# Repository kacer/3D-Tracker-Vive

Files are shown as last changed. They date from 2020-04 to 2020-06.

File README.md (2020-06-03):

# 3D Tracker compatible with HTC Vive
This little device is capable of tracking its position in the world. The tracked position is then sent over BLE to the smartphone. The [mobile app](https://github.com/kacer/3D-Tracker-Vive-Android) was created for this purpose and renders the positions of all connected 3D trackers. For tracking 3D Tracker uses two HTC Base Stations which are part of the HTC Vive set for VR. For now, the tracker uses HTC Base Station 1.0 but HW is ready for HTC Base Station 2.0. This project came to the world within my master's thesis. The idea of position calculation is based on repo [vive-diy-position-sensor](https://github.com/ashtuchkin/vive-diy-position-sensor). 

The dimensions of the 3D tracker are 6.3x4.7 cm and can be worn like a watch. The 3D tracker itself looks: 
| Tracker1 | Tracker |
| --- | --- |

The demo of position tracking by two 3D trackers on YouTube:
The demo of position tracking by two 3D trackers (https://www.youtube.com/watch?v=TOYSWDCKwdk)

## Hardware
The 3D tracker is based on **nRF52840** and uses as a sensor of IR light **TS4231 + photodiode BPW34S**. For now, only one sensor is used and thus calibration of positions of HTC Base Station must be taken from SteamVR through this utility [vive-diy-position-sensor-geometry-getter](https://github.com/ashtuchkin/vive-diy-position-sensor-geometry-getter). This utility prints to console the geometry of HTC Base Stations which is consists of position and rotation matrix. This data are then copied and save to txt file. After that, the txt file with geometry is copied to the smartphone and through the [mobile app](https://github.com/kacer/3D-Tracker-Vive-Android) is sent to 3D trackers. Because nRF52840 was used additional sensors are possible to add.

## Getting started
The firmware of 3D Tracker was written in [PlatformIO](https://platformio.org/) with Arduino framework in C++. I recommend using the Visual Studio Code for developing. The installation process of PlatfromIO is pretty simple. Just install it like an extension of the VS Code. Then clone this repository, open it in VS Code, build and upload to your board.

### Uploading firmware into board
I used a [development kit with nRF52840](https://www.nordicsemi.com/Software-and-Tools/Development-Kits/nRF52840-DK) from Nordic Semiconductor for burning firmware into a chip. Wiring was following: programming-custom-board

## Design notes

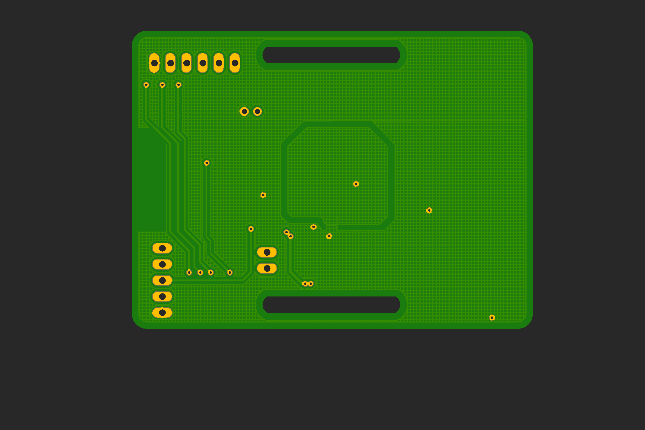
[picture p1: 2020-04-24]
hardware/exports/3D-tracker-bottom-render.png

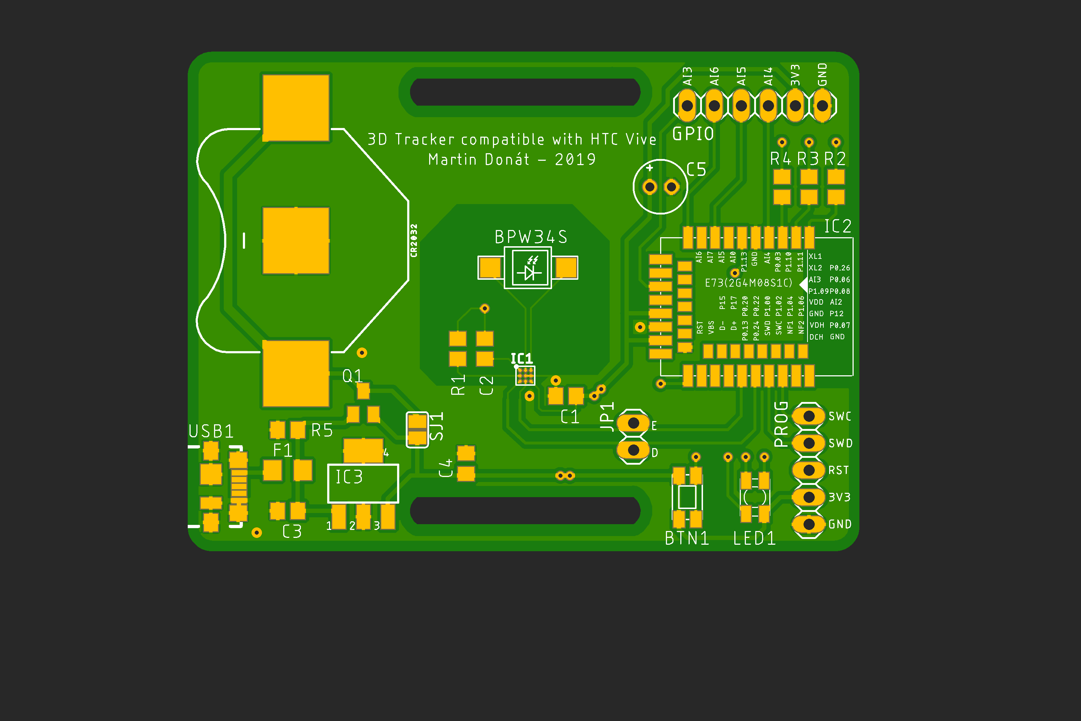
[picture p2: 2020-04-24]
hardware/exports/3D-tracker-top-render.png

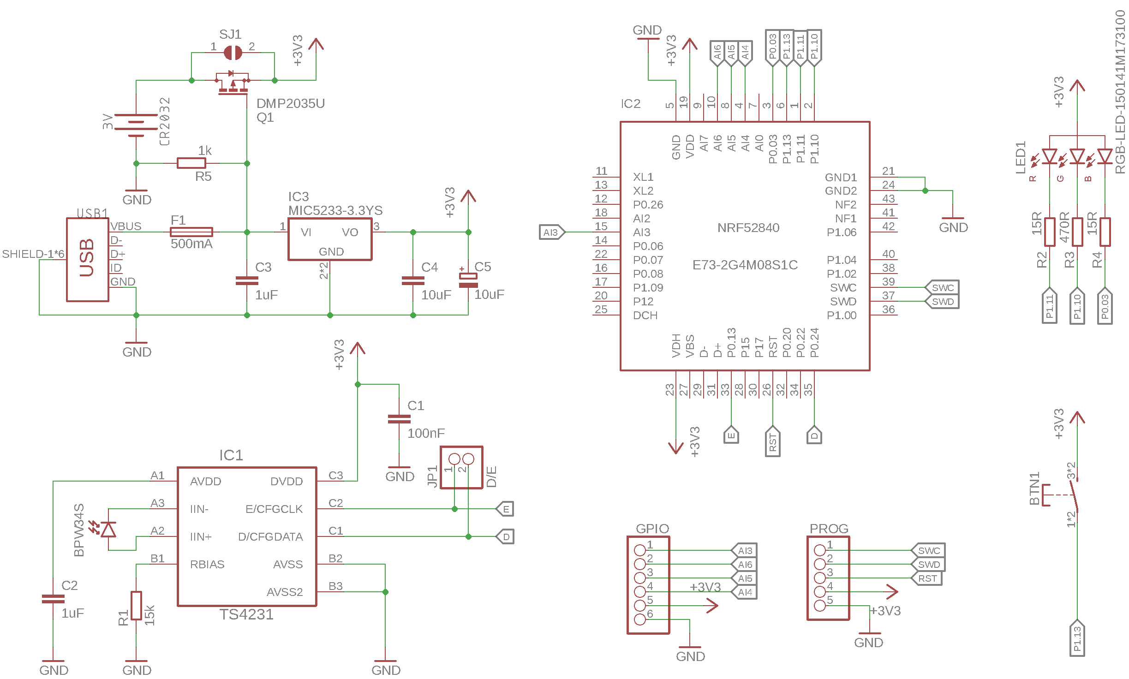
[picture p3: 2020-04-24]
hardware/exports/3D-tracker-schema.png

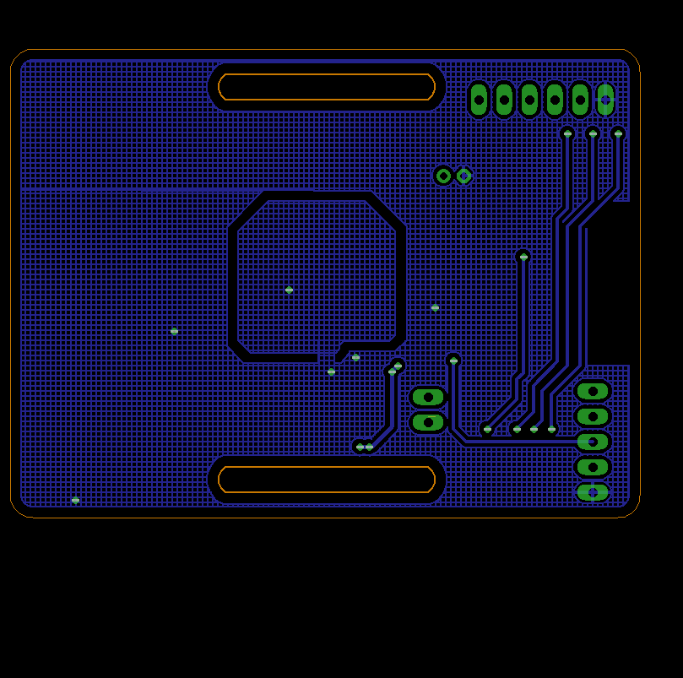
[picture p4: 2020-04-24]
hardware/exports/3D-tracker-bottom-layer.png

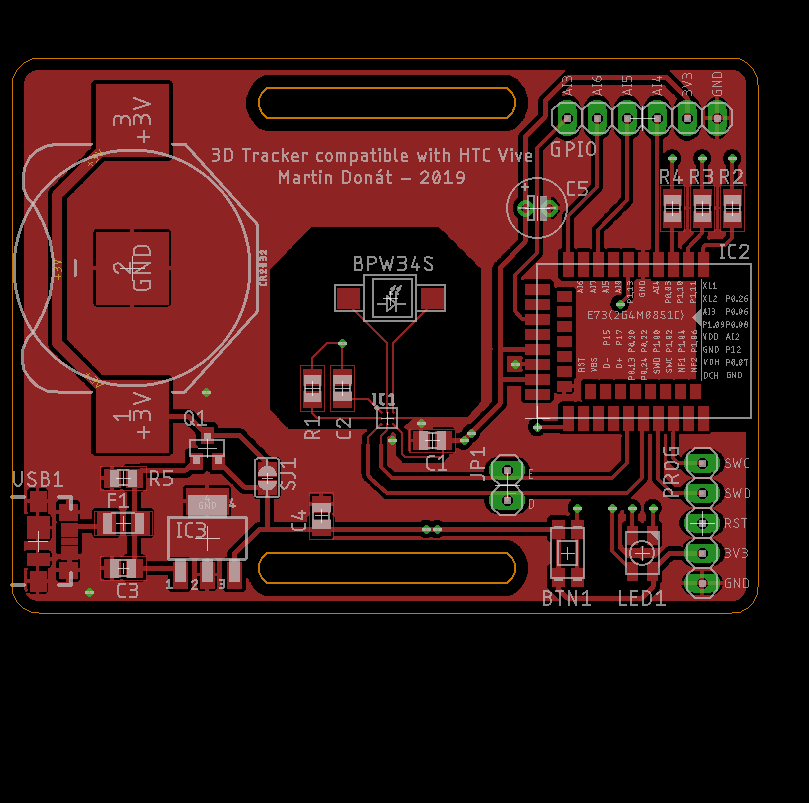
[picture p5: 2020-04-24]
hardware/exports/3D-tracker-top-layer.png

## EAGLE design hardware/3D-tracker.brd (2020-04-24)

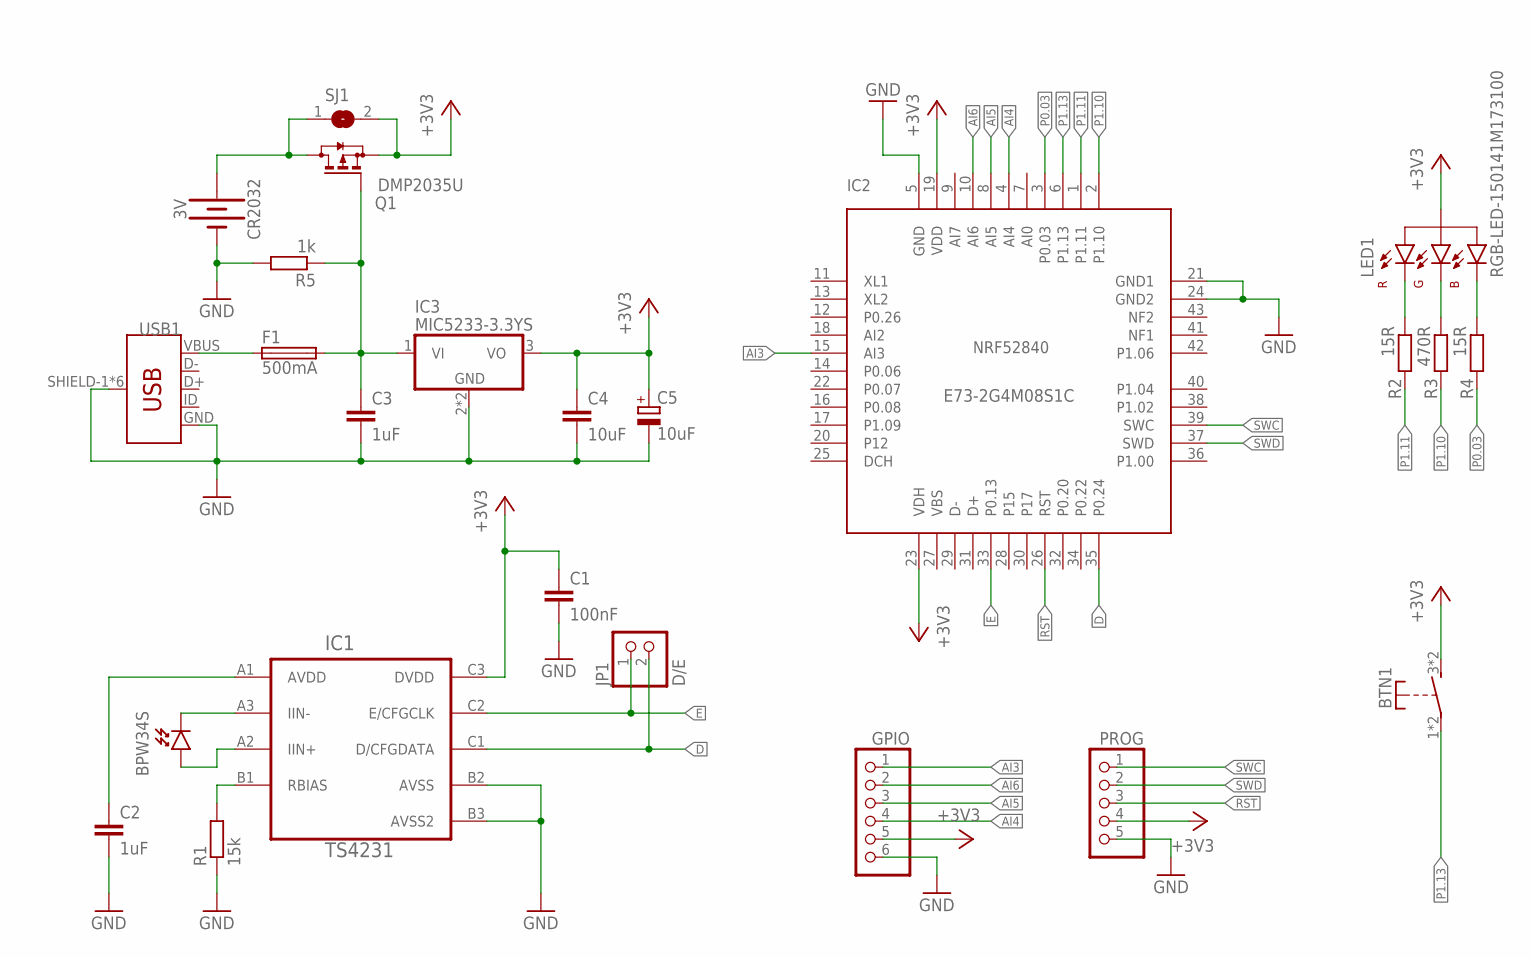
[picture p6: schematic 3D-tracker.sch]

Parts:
BPW34S: JONNEW_PHOTODIODE_VBPW34S; JONNEW_VBPW34S
BTN1: SWITCH-SMD
C1: 100nF; C0805
C2, C3: 1uF; C0805
C4: 10uF; C0805
C5: 10uF; E2-5
CR2032: 3V; BATTCON_20MM
F1: 500mA; R1206
GPIO: PINHD-1X6; 1X06
IC1: TS4231; JONNEW_WLCSP3X3
IC2: NRF52840; PE73(2G4M08S1C)
IC3: MIC5233-3.3YS; SOT223
JP1: D/E; 1X02
LED1: RGB-LED-150141M173100; LED4-3.5X2.8
PROG: PINHD-1X5; 1X05
Q1: DMP2035U; SOT23
R1: 15k; R0805
R2, R4: 15R; R0805
R3: 470R; R0805
R5: 1k; R0805
SJ1: SJ
USB1: USB-B-MICRO-SMD; MICRO-USB-B-SMD

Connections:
+3V: CR2032.1 (+), CR2032.3 (+), Q1.3 (D), SJ1.1
+3V3: BTN1.3 (S), BTN1.4 (S), C1.1, C4.1, C5.+, GPIO.5, IC1.C3 (DVDD), IC2.19 (VDD), IC2.23 (VDH), IC3.3 (VO), LED1.1 (ALL-A), PROG.4, Q1.2 (S), SJ1.2
+5V: C3.1, F1.2, IC3.1 (VI), Q1.1 (G), R5.1
AI3: GPIO.1, IC2.15 (AI3)
AI4: GPIO.4, IC2.4 (AI4)
AI5: GPIO.3, IC2.8 (AI5)
AI6: GPIO.2, IC2.10 (AI6)
AVDD: C2.1, IC1.A1 (AVDD)
D: IC1.C1 (D/CFGDATA), IC2.35 (P0.24), JP1.2
E: IC1.C2 (E/CFGCLK), IC2.33 (P0.13), JP1.1
GND: C1.2, C2.2, C3.2, C4.2, C5.-, CR2032.2 (-), GPIO.6, IC1.B2 (AVSS), IC1.B3 (AVSS2), IC2.5 (GND), IC2.21 (GND1), IC2.24 (GND2), IC3.2 (GND), IC3.4 (GND), PROG.5, R1.1, R5.2, USB1.GND, USB1.SHIELD-1 (SHIELD), USB1.SHIELD-2 (SHIELD), USB1.SHIELD-3 (SHIELD), USB1.SHIELD-4 (SHIELD), USB1.SHIELD-5 (SHIELD), USB1.SHIELD-6 (SHIELD)
IIN+: BPW34S.A, IC1.A2 (IIN+)
IIN-: BPW34S.C, IC1.A3 (IIN-)
unnamed: LED1.2 (BLUE-C), R4.1
unnamed: LED1.3 (RED-C), R2.1
unnamed: LED1.4 (GREEN-C), R3.1
P0.03: IC2.3 (P0.03), R4.2
P1.10: IC2.2 (P1.10), R3.2
P1.11: IC2.1 (P1.11), R2.2
P1.13: BTN1.1, BTN1.2, IC2.6 (P1.13)
RBIAS: IC1.B1 (RBIAS), R1.2
RST: IC2.26 (RST), PROG.3
SWC: IC2.39 (SWC), PROG.1
SWD: IC2.37 (SWD), PROG.2
VBUS: F1.1, USB1.VBUS

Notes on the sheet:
E73-2G4M08S1C

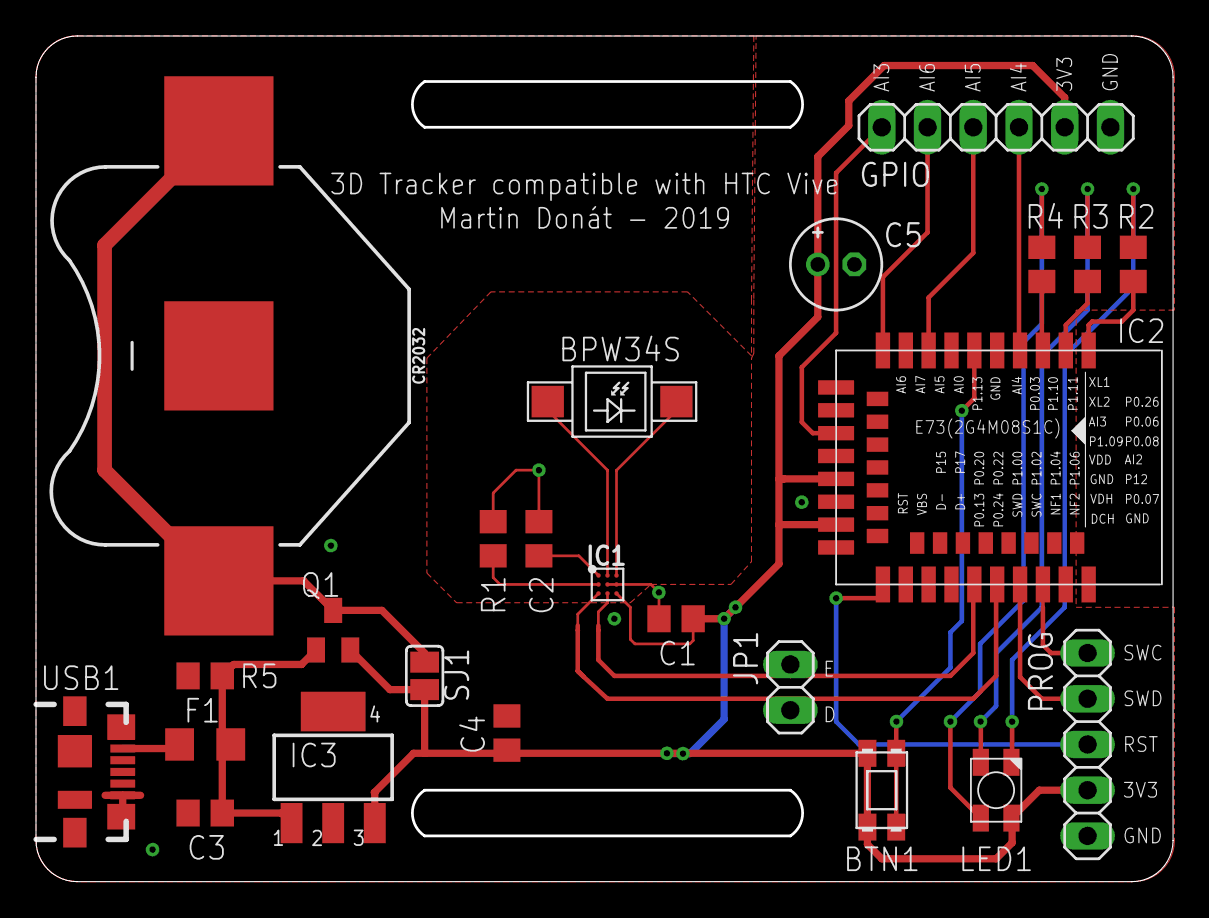
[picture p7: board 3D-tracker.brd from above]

Board: 2 copper layers, 63.2 x 47.0 mm, 24 parts (0 on the bottom side), 25 nets.

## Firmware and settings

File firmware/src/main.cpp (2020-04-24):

#include <Arduino.h>
#include <SPI.h>
#include <BLEPeripheral.h>
#include "tracker_gpio.h"
#include "position_calculator.h"
#include "pulse_processor.h"
#include "bluetooth.h"
#include "led_driver.h"


void anglesCb(float32_t *angles);
void baseStationGeometryCB(BaseStation *baseStations);

PulseProcessor pulseProcessor(anglesCb);
PositionCalculator positionCalculator = PositionCalculator();
Bluetooth* bluetooth = Bluetooth::getInstance();
LedDriver ledDriver = LedDriver();

const uint16_t MAX_POSITION_UPDATE_DELAY = 1000; // 1s
const uint16_t LIGHT_TIMEOUT = 500; // 500 ms
uint32_t lastPositionUpdateMillis;
bool receivingCoordinates = false;
bool lightDetected = false;


extern "C" {  //important; otherwise irq handler won't be called
    void GPIOTE_IRQHandler(void) {
        if(NRF_GPIOTE->EVENTS_IN[0] != 0) {
            NRF_GPIOTE->EVENTS_IN[0] = 0;
            // raising edge
            lightDetected = true;
        }

        if(NRF_GPIOTE->EVENTS_IN[1] != 0) {
            NRF_GPIOTE->EVENTS_IN[1] = 0;
            // falling edge
            uint32_t raising_time = NRF_TIMER1->CC[0];
            uint32_t falling_time = NRF_TIMER1->CC[1];
            uint32_t pulse_length_ticks = falling_time - raising_time;

            Pulse pulse = {raising_time, pulse_length_ticks};
            pulseProcessor.addPulse(pulse);
        }
    }
}

void anglesCb(float32_t *angles) {
    vec3d xyz;
    uint8_t result = positionCalculator.calcPosition(angles, xyz);
    
    switch(result) {
        case CALCULATION_SUCCESS:
            lastPositionUpdateMillis = millis();
            bluetooth->sendPosition(xyz);
            ledDriver.showTracking();
            receivingCoordinates = true;
            
            #ifdef DEBUG
                Serial.print(xyz[0], 6);
                Serial.print(" ");
                Serial.print(xyz[1], 6);
                Serial.print(" ");
                Serial.println(xyz[2], 6);
            #endif
            break;
        case BASESTATIONS_NOT_SET:
            ledDriver.showGeometryNotSet();
            receivingCoordinates = false;
            break;
        case CALCULATION_FAILED:
            ledDriver.showFailed();
            receivingCoordinates = false;
            break;
    }
}

void baseStationGeometryCB(BaseStation *baseStations) {
    positionCalculator.setBaseStationsGeometry(baseStations[0], baseStations[1]);
    // clear state showing that geometry is not set
    receivingCoordinates = true;
    ledDriver.showTracking();
}

bool waitForLight(uint16_t timeout) {
    uint32_t startTime = millis();
    
    while(millis() - startTime < timeout) {
        if(lightDetected) {
            return true;
        }
    }

    return false;
}

void setup() {
    Serial.setPins(A_PIN_UART_RX, A_PIN_UART_TX);
    Serial.begin(115200);

    bluetooth->setBaseStationGeometryCB(baseStationGeometryCB);
    bluetooth->setup();
    ledDriver.setup();

    // set pull-down for button to prevent accidental damage
    // the button is not used for now
    pinMode(PIN_BTN1, INPUT_PULLDOWN);

    // setting GPIOTE channels for raising and falling edge
    uint8_t pin_D = PIN_D_TS4231.number; 
    uint8_t port_pin_D = PIN_D_TS4231.port;
    uint8_t gpiote_channel_raising = 0;
    uint8_t gpiote_channel_falling = 1;
    NRF_GPIOTE->CONFIG[gpiote_channel_raising] = ((uint32_t) GPIOTE_CONFIG_MODE_Event << GPIOTE_CONFIG_MODE_Pos)
                                                | ((uint32_t) pin_D << GPIOTE_CONFIG_PSEL_Pos)
                                                | ((uint32_t) port_pin_D << 13UL)   // Bit PORT starts at 13, could be skipped
                                                | ((uint32_t) GPIOTE_CONFIG_POLARITY_LoToHi << GPIOTE_CONFIG_POLARITY_Pos);
    NRF_GPIOTE->CONFIG[gpiote_channel_falling] = ((uint32_t) GPIOTE_CONFIG_MODE_Event << GPIOTE_CONFIG_MODE_Pos)
                                                | ((uint32_t) pin_D << GPIOTE_CONFIG_PSEL_Pos)
                                                | ((uint32_t) port_pin_D << 13UL)   // Bit PORT starts at 13, could be skipped
                                                | ((uint32_t) GPIOTE_CONFIG_POLARITY_HiToLo << GPIOTE_CONFIG_POLARITY_Pos);
    NRF_GPIOTE->INTENSET = ((uint32_t) GPIOTE_INTENSET_IN0_Enabled << GPIOTE_INTENSET_IN0_Pos)
                            | ((uint32_t) GPIOTE_INTENSET_IN1_Enabled << GPIOTE_INTENSET_IN1_Pos);
    NVIC_EnableIRQ(GPIOTE_IRQn);

    // config TIMER1 for capturing timestamps of rising and falling edges from GPIOTE
    NRF_TIMER1->MODE = TIMER_MODE_MODE_Timer;
    NRF_TIMER1->PRESCALER = 0;    // 16MHz
    NRF_TIMER1->BITMODE = TIMER_BITMODE_BITMODE_32Bit;

    // config PPI for transfering events of rising/falling edge on pin D to TIMER1 for capturing timestamps
    NRF_PPI->CH[gpiote_channel_raising].EEP = (uint32_t) &NRF_GPIOTE->EVENTS_IN[gpiote_channel_raising];
    NRF_PPI->CH[gpiote_channel_raising].TEP = (uint32_t) &NRF_TIMER1->TASKS_CAPTURE[gpiote_channel_raising];
    NRF_PPI->CH[gpiote_channel_falling].EEP = (uint32_t) &NRF_GPIOTE->EVENTS_IN[gpiote_channel_falling];
    NRF_PPI->CH[gpiote_channel_falling].TEP = (uint32_t) &NRF_TIMER1->TASKS_CAPTURE[gpiote_channel_falling];
    NRF_PPI->CHENSET = ((uint32_t) PPI_CHENSET_CH0_Enabled << PPI_CHENSET_CH0_Pos)
                    | ((uint32_t) PPI_CHENSET_CH1_Enabled << PPI_CHENSET_CH1_Pos);

    // start TIMER1
    NRF_TIMER1->TASKS_START = 1;

    if(!waitForLight(LIGHT_TIMEOUT)) {
        ledDriver.showFailed();
    } else {
        ledDriver.showGeometryNotSet();
    }
}

void loop() {
    pulseProcessor.loop();
    bluetooth->poll();
    ledDriver.loop();
    
    if(receivingCoordinates && (millis() - lastPositionUpdateMillis) > MAX_POSITION_UPDATE_DELAY) {
        // tracker was occluded
        ledDriver.showTrackingTimeout();
    }
}

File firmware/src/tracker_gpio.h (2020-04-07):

#pragma once

#include <nrf.h>
#include <wiring_constants.h>
#include <Arduino.h>

#define NRF_P1_BASE                     0x50000300UL
#define NRF_P1                          ((NRF_GPIO_Type           *) NRF_P1_BASE)

#define PIN_RED_LED     GPIO_PIN {1, 11}  //P1.11
#define PIN_GREEN_LED   GPIO_PIN {1, 10}  //P1.10
#define PIN_BLUE_LED    GPIO_PIN {0, 3}   //P0.03

#define PIN_BTN1        GPIO_PIN {1, 13}  //P1.13

#define PIN_E_TS4231    GPIO_PIN {0, 13}  //P0.13
#define PIN_D_TS4231    GPIO_PIN {0, 24}  //P0.24

#define PIN_AI3         GPIO_PIN {0, 5}   //P0.05        
#define PIN_AI4         GPIO_PIN {0, 28}  //P0.28
#define PIN_AI5         GPIO_PIN {0, 29}  //P0.29
#define PIN_AI6         GPIO_PIN {0, 30}  //P0.30

#define PIN_RST         GPIO_PIN {0, 18}  //P0.18
//#define PIN_SWD         GPIO_PIN {0, 0}   //SWDIO
//#define PIN_SWC         GPIO_PIN {0, 0}   //SWDCLK


#define A_PIN_AI3           20          
#define A_PIN_AI4           16
#define A_PIN_AI5           17
#define A_PIN_AI6           18

#define A_PIN_E_TS4231      2
#define A_PIN_D_TS4231      12

#define A_PIN_UART_TX       A_PIN_AI4       //AI4
#define A_PIN_UART_RX       PIN_SERIAL_RX   //DEFAULT RX SERIAL PIN


typedef struct {
    uint8_t port;
    uint32_t number;
} GPIO_PIN;

/**
 * \brief Configures the specified pin to behave either as an input or an output.
 *
 * \param pin The pin whose mode you wish to set
 * \param mode Can be INPUT, OUTPUT, INPUT_PULLUP or INPUT_PULLDOWN
 */
extern void pinMode(GPIO_PIN pin, uint32_t mode);


/**
 * \brief Write a HIGH or a LOW value to a digital pin.
 *
 * If the pin has been configured as an OUTPUT with pinMode(), its voltage will be set to the
 * corresponding value: 5V (or 3.3V on 3.3V boards) for HIGH, 0V (ground) for LOW.
 *
 * If the pin is configured as an INPUT, writing a HIGH value with digitalWrite() will enable an internal
 * 20K pullup resistor (see the tutorial on digital pins). Writing LOW will disable the pullup. The pullup
 * resistor is enough to light an LED dimly, so if LEDs appear to work, but very dimly, this is a likely
 * cause. The remedy is to set the pin to an output with the pinMode() function.
 *
 * \note Digital pin PIN_LED is harder to use as a digital input than the other digital pins because it has an LED
 * and resistor attached to it that's soldered to the board on most boards. If you enable its internal 20k pull-up
 * resistor, it will hang at around 1.7 V instead of the expected 5V because the onboard LED and series resistor
 * pull the voltage level down, meaning it always returns LOW. If you must use pin PIN_LED as a digital input, use an
 * external pull down resistor.
 *
 * \param pin the pin
 * \param value HIGH or LOW
 */
extern void digitalWrite(GPIO_PIN pin, uint32_t value);

/**
 * \brief Reads the value from a specified digital pin, either HIGH or LOW.
 *
 * \param pin The digital pin you want to read (int)
 *
 * \return HIGH or LOW
 */
extern int digitalRead(GPIO_PIN pin);

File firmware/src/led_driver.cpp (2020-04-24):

#include "led_driver.h"

void LedDriver::showFailed(void) {
    if(showingState == STATE_FAILED) {
        return;
    }

    reset();
    showingState = STATE_FAILED;
}

void LedDriver::showGeometryNotSet(void) {
    if(showingState == STATE_GEOMETRY_NOT_SET) {
        return;
    }

    reset();
    showingState = STATE_GEOMETRY_NOT_SET;
}

void LedDriver::showTracking(void) {
    if(showingState == STATE_TRACKING) {
        return;
    }

    reset();
    showingState = STATE_TRACKING;
}

void LedDriver::showTrackingTimeout(void) {
    if(showingState == STATE_TRACKING_TIMEOUT) {
        return;
    }

    reset();
    showingState = STATE_TRACKING_TIMEOUT;
}

void LedDriver::turnAllOf(void) {
    reset();
}

void LedDriver::loop(void) {
    const LedTimings *ledTiming;
    uint8_t totalTimings;
    switch(showingState) {
        case STATE_ALL_OFF:
            return;
        case STATE_FAILED:
            ledTiming = failedTimings;
            totalTimings = sizeof(failedTimings) / sizeof(*ledTiming);
            break;
        case STATE_TRACKING:
            ledTiming = trackingTimings;
            totalTimings = sizeof(trackingTimings) / sizeof(*ledTiming);
            break;
        case STATE_TRACKING_TIMEOUT:
            ledTiming = trackingTimeoutTimings;
            totalTimings = sizeof(trackingTimeoutTimings) / sizeof(*ledTiming);
            break;
        case STATE_GEOMETRY_NOT_SET:
            ledTiming = geometryNotSetTimings;
            totalTimings = sizeof(geometryNotSetTimings) / sizeof(*ledTiming);
            break;
        default:
            return;
    }

    uint32_t currentMillis = millis();
    if(!startMillis) {
        // the start of whole cycle
        startMillis = currentMillis;
        isLedTurnOn = true;
    }

    if(isLedTurnOn) {
        // LED is turned on
        digitalWrite(ledTiming[timingsIndex].led, LOW);
        if(currentMillis - startMillis > ledTiming[timingsIndex].turnOn) {
            // turn off LED
            isLedTurnOn = false;
            startMillis = currentMillis;
            digitalWrite(ledTiming[timingsIndex].led, HIGH);
        }
    } else {
        // LED is turned off
        digitalWrite(ledTiming[timingsIndex].led, HIGH);
        if(currentMillis - startMillis > ledTiming[timingsIndex].turnOff) {
            // turn on LED
            isLedTurnOn = true;
            startMillis = currentMillis;
            //end of cycle -> move index to next led timings
            timingsIndex = ++timingsIndex % totalTimings;
            digitalWrite(ledTiming[timingsIndex].led, LOW);
        }
    }
}

void LedDriver::setup(void) {
    reset();
    pinMode(PIN_RED_LED, OUTPUT);
    pinMode(PIN_GREEN_LED, OUTPUT);
    pinMode(PIN_BLUE_LED, OUTPUT);
}

void LedDriver::reset(void) {
    showingState = STATE_ALL_OFF;
    startMillis = 0;
    isLedTurnOn = false;
    timingsIndex = 0;
    digitalWrite(PIN_RED_LED, HIGH);
    digitalWrite(PIN_GREEN_LED, HIGH);
    digitalWrite(PIN_BLUE_LED, HIGH);
}

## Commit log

2020-03-04 Initial commit - add hw design files, basic .gitignore config, empty source code
    [3D-tracker.brd, 3D-tracker.sch]
2020-03-14 Add calculation of angles between sensor and base stations
2020-03-25 Fix bugs with sync pulses and computing 2 angles in one cycle
    Add code that checks every start of cycle with 2 sync pulses.
    Add check for sweep pulses inside of computeAngle function. Maybe could be better store every "sweep" pulse in array and at the end of cycle compute angle with maximum length of "sweep" pulse from array.
    [pulse_processor.h]
2020-04-07 Add Bluetooth and led driver
    Contains debug prints
2020-04-24 Update electrical scheme, add gerber file, add hw images
    [3D-tracker.brd, 3D-tracker.sch]
2020-04-24 Remove debug prints, edit docs a little bit, some renames
2020-04-24 Set default pull-down for button to prevent accidental damage
    [main.cpp]
2020-04-30 Rename zip with gerber files for clarification
